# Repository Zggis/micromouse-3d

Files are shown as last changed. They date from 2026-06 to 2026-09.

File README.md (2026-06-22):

# :mouse2: Micromouse 3D

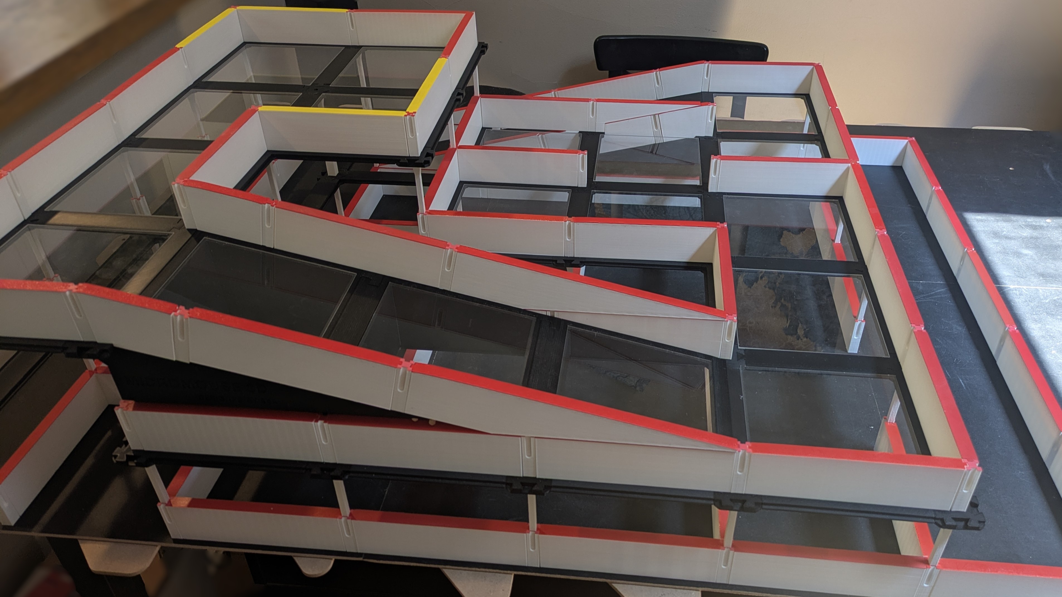
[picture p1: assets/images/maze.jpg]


Micromouse 3D builds off the traditional Micromouse event by using a multi-level maze.
The maze includes ramps that allow robots to travel between levels of the maze to reach the goal.
The cell dimensions are the same, most Micromouse robots won't require hardware changes to participate.
MM3D provides new challenges for students and enthusiasts over traditional Micromouse events.

If you are planning to build a MM3D maze, or participate in a MM3D event please star :star: this repository.
This will help me gauge interest in this project.

## :building_construction: [Maze Construction](./maze/README.md)

MM3D uses 3D printed parts to assemble the ramp and upper levels of the maze.
The parts have been designed to fit on standard 250mm size 3D printers.
All the print files are included in this repository, you can start [here](/maze/README.md) to build the maze.

> [!IMPORTANT]
> If you are planning to participate in a MM3D event,
> it is highly recommended you build a small test maze with a ramp so you can calibrate your robot.

## :scroll: [Rules](./rules/README.md)

Similar to traditional Micromouse, the rules for a MM3D event can be tuned to the level of difficulty desired. Two events are outlined in this repository 'Pyramid' and 'Bridge'. These events serve as a template which competition organizers can build on and make adjustments as needed.

Due to maze constraints, robots must meet the following size constraints for MM3D:
- Mice must be less than 12cm high
- Mice cannot reach over the walls

## Version Compatibility

>[!WARNING]
> Parts from different versions may not be compatible as updates are made.

Releases are published under a semantic version which you can find in [global.json](./global.json).
You can switch the version by selecting a different tag in the repository.
Release notes for each version can be found in [Releases.](https://github.com/Zggis/micromouse-3d/releases)

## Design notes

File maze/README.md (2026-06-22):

# :hammer: Building the Maze

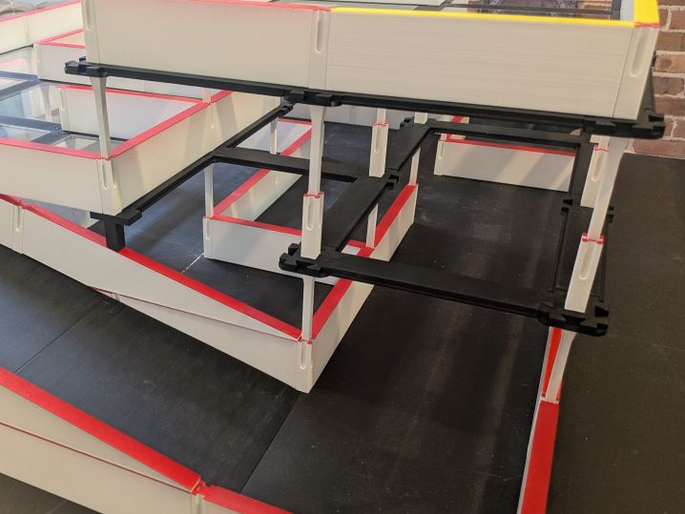
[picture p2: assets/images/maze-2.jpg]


MM3D can be used as a stand-alone maze or an add-on to an existing maze.

If you do not have a Micromomouse maze, you can use the parts [here](./base/) to create your base level.

All the 3D print files for MM3D are available in the subdirectories. Additional README files can be found in each directory explaining what the part is used for and the recommended print settings for it.

## :page_with_curl: Bill of Materials

In addition to parts you can 3D print, you can purchase the following:

| Part | Retail Link | |
|---|---|---|
| 15/64" x 1-1/4" (6mm) Wooden Dowel Pins | [Amazon](https://a.co/d/0eMDBzNE) | I recommend the RHINO brand to ensure the tolerances are compatible with the 3D printed parts. |
| Cyanoacrylate Glue (Super Glue) | [Amazon](https://a.co/d/03UX3yRg) | Used to glue pegs into the 3D printed pillars. |
| 6"x6" 1/8" Thick Clear Acrylic Sheets | [Amazon](https://a.co/d/02cTOcOn) | These are <strong>OPTIONAL</strong>, they can be substituted with a 3D printed [cell inserts](./inserts/). Using them is beneficial as it reduces 3D printing and allows you to see robots traveling on the levels below. |
| Base Tiles | [Shopify](https://swglobes.com/products/micromouse-maze-tile) | These are <strong>OPTIONAL</strong>, if you don't already have a maze they can be substituted with the 3D printed [base](./base/). These tiles are great for large mazes and fast robots that may not be able to perform on the 3D printed base. |

## :printer: Printing Guidelines

### File Types

This repository includes STL and STEP format files for 3D parts. STEP format includes more detail and should be used over STL if your slicer supports them. Popular slicers such as Bamboo Studio, Prusa Slicer, and Orca Slicer support STEP files.

### Print Settings & Orientation

If using the STEP files, slicers will ignore any coordinate system included in the file,
so you will need to orient them correctly using the recommended orientation included with the print settings.
These settings can be found in the README files in the corresponding component directories.
If you are confused about a part's print orientation, open the STL file which will be oriented correctly in the viewer.

### Dowel Holes

Some parts require you to insert 6mm wooden dowel pins.
The pins mentioned above can vary in diameter, I have measured between 5.60mm - 5.85mm.
To help accommodate this variation, all parts requiring pins are available with three different size holes.

> [!TIP]
> You can print the dowel test part in this directory to help you determine which size to use for which part.
> For the pillars, I recommend starting with a loose fit.
> For the vertex and ramp pieces, I recommend a very snug fit.
> From my experience, a batch of dowels is pretty consistent.
> If you switch batches, you should recheck the fit.

| Filename Suffix | Dowel Hole Diameter |
|---|---|
| _60 | 6.0mm |
| _61 | 6.1mm |
| _62 | 6.2mm |

> [!NOTE]
> If your pins don't work with these tolerances,
> you can [request a new size](https://github.com/zggis/micromouse-3d/issues/new?template=new-dowel-hole-diameter-request.md)
> and I will try to accommodate.
> I will only consider this for 6mm pins that are equal length to those in the bill of materials.

### Material

I printed all the parts in PLA. Other materials may cause parts to shrink and impact the tolerances. You can try to scale the parts up in your slicer to account for this, but I have not tested it.

> [!WARNING]
> Try to keep printed parts away from direct sunlight,
> the connectors in particular can warp if they are exposed to heat.

### Printer Calibration

Some of the printed parts rely on tolerances of 0.1mm.
I suggest printing a few [lattice](./lattice/) parts to check the tolerances
and make sure they fit together correctly before printing parts in bulk.
If you find the tolerances are too small or too large, try the following:
- Change your printer's nozzle. After enough prints, nozzles wear out and can't extrude lines thin enough to meet their specification.
- Perform a skew calibration on your printer. All of my printers have been calibrated using the free Calistar method you can find [here](https://github.com/dirtdigger/fleur_de_cali).

## Components

There are four main components to MM3D:

### [Ramp](./ramp/)

The MM3D ramp is divided into three printed sections which slide together.
You generally only need one ramp per level, but some event types may require more.

### [Supports](./supports/)

There are two ways you can support the upper levels of the maze:
+ Using pillars with integrated support. This requires less printing and does not take up cell space. They can be used on upper levels to support levels 3 and up. If your base uses 6mm diameter holes (or you are using the printed [base](./base/)), you can use these to support the second level as well.
+ Using the elevated cell which sits in an open cell. This requires more printing, but is compatible with any maze that meets the standard Micromouse dimensions.

### [Lattice Structure](./lattice/)

The lattice is made from connectors and vertices which form the cell grid on upper levels.

### [Cell Inserts](./inserts/)

For the cell inserts, you can use 6"x6" 1/8"
thick plastic sheets such as the clear acrylic sheets from the bill of materials above,
or you can print the cell inserts.

### OPTIONAL Components

[Special parts](./special/) and [Edge parts](./edges/) are optional to create more cells and improve aesthetic. Additional details can be found in their READMEs.

## Assembly

Once you have all the components, the assembly is pretty straightforward. Here are a few points:

- The ramp pieces slide together and can be inserted into the maze sliding the top piece up against a wall. The lower ramp edge should be right at the threshold of the cell.
- Make sure to orient the connectors and vertices correctly, the dovetails should face up, and the ledge on the connectors should face up to cradle the cell inserts.
- If using the support pillars, insert a pillar into the vertex before resting it on the support pillar.
- When assembling the lattice structure on top of support pillars, it may seem flimsy at first,
but as you connect everything it will become more rigid.

> [!TIP]
> You may be tempted to build your maze like a parking garage, maximizing the number of cells on each level.
> This makes it more difficult to calibrate a robot's IR sensors, and extract a robot when it becomes stuck.
> Try building mazes with empty spaces between the levels and create balconies.
> These mazes still have the challenge of MM3D, but make it easier to see robots traveling through them.
> Every vertex doesn't need four connectors, consider removing some to create more space to see and extract robots.
> The image of the maze at the top of this page is a good example.

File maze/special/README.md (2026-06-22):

# Special Parts

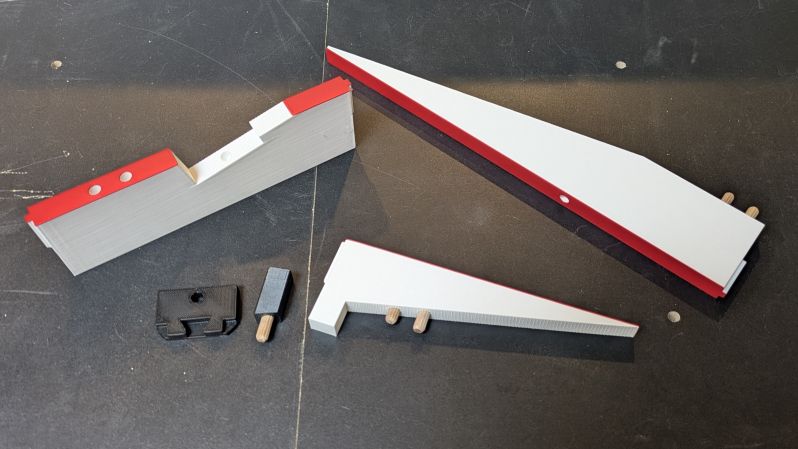
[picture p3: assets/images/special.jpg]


These parts are <strong>optional.</strong> They allow you
to add cells adjacent to and above ramps which would otherwise be unusable.
They may not be ideal for competition mazes,
but for test mazes that have a limited footprint they create more cells to work with.

## Print Settings

### Walls

- Middle walls should be printed upright, with the red surface on top. The other walls should be printed upside down with the red surfaces on the bed.

| Setting | Value | Reason |
|---|---|---|
| Perimeters / Wall Loops | 2 | |
| Infill | 10% | Using less than 10% may impact reflectivity |
| Solid Layers - Top & Bottom | 3 | No need for more than 3 on these parts, make sure your minimum shell thickness is small enough to support this. |
| Infill Type | Grid  | The walls are slightly translucent, using this infill pattern gives the best aesthetic and the most consistent reflectiveness. |

### Vertex and Vertex Spacer

- Vertex should be printed as it is in the maze with the dovetails facing up.
- Vertex spacer should be oriented, so it stands up straight with the slanted surface on top.

| Setting | Value | 
|---|---|
| Perimeters / Wall Loops | 3 | 
| Infill | 15% | 
| Solid Layers - TOP | 5 |

## Assembly

6mm dowel pins should be glued into the ramp-wall-half, not the ramp-wall-middle.

A dowel can be glued into the vertex spacer's slanted face.

2 drops of glue in each hole should be all that is needed.
<strong>The pins should be pressed in firmly, so they bottom out.</strong>

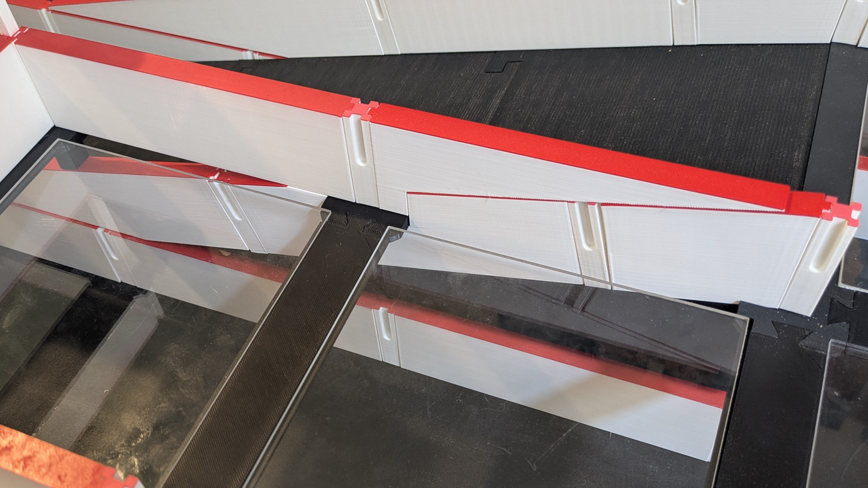
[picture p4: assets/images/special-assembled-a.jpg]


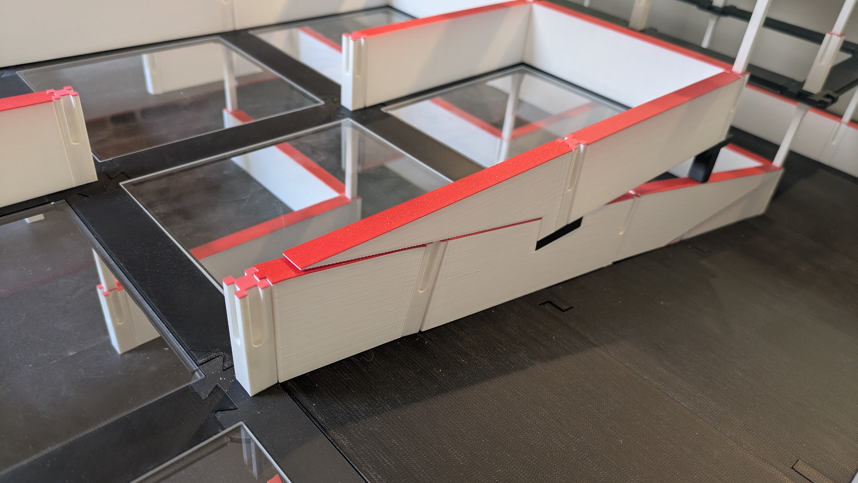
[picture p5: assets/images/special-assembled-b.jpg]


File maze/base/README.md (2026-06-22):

# Base Maze

If you don't already have a Micromouse maze, this vertex can be used with the [lattice](../lattice/) connectors and [cell inserts](../inserts/) to create a base level. This vertex is thicker to allow pillars to anchor into them without their pegs protruding.

Since it uses a 6mm peg hole, it is compatible with the support pillars, removing the need to use elevated cells.

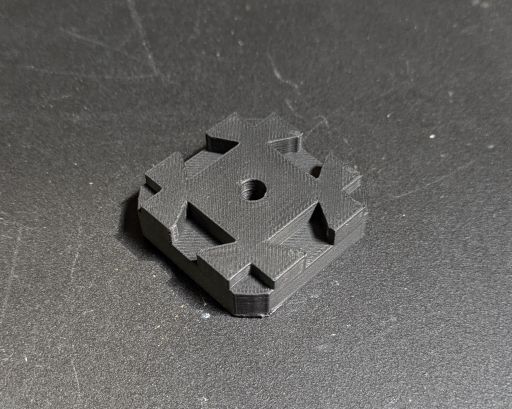
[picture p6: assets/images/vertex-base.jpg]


If you prefer not to the 3D print the base,
[these base tiles](https://swglobes.com/products/micromouse-maze-tile) are fully compatible with MM3D.

## Print Settings

Orient the part so the dovetails face up as they would when assembled.

| Setting | Value |
|---|---|
| Perimeters / Wall Loops | 2 |
| Infill | 5% | 
| Solid Layers - TOP | 5 |

## Assembly

> [!NOTE]
> If you are placing a ramp in a cell, inserts are not required underneath,
> the ramp can straddle the connectors.

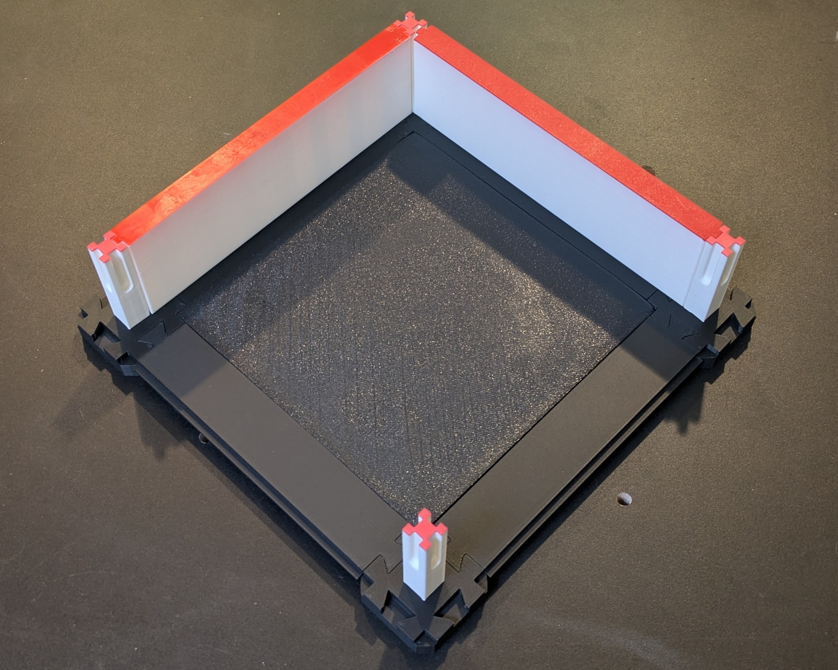
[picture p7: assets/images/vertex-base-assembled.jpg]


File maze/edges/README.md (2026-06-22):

# Edges

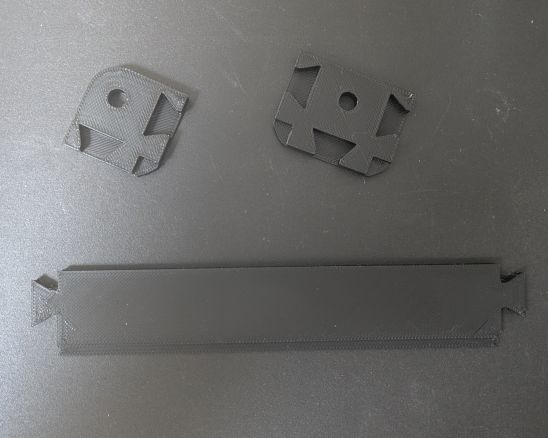
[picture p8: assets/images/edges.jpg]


These parts are <strong>optional.</strong> They can be used for the edges of the lattice to improve the aesthetic and save a small amount of filament.

## Print Settings

Use the same print settings as the corresponding [lattice](../lattice/) parts.

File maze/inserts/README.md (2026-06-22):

# Cell Insert

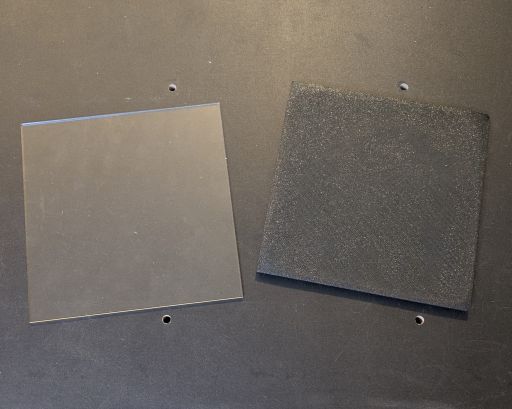
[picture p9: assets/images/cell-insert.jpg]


>[!NOTE]
> Cell inserts are not required for the elevated cell, or cells that have a ramp in them.

## Print Settings

Orient the part upside down with the top surface on the bed.

| Setting | Value | Reason |
|---|---|---|
| Perimeters / Wall Loops | 2 | |
| Infill | 5% | |
| Solid Layers - TOP | 5 | |
| Brim | 4mm | The corners have a tendency to warp off the bed, if you have this problem try using a 4mm brim |

## Plastic Panels

Any 1/8" thick 6"x6" panel should work as an insert. Clear acrylic panels are great because they allow you to see the robot as it travels on the levels below.

>[!WARNING]
> Cell inserts must be dimensionally accurate with high precision.
> Modern 3D printers have no trouble achieving this.
> If you are considering plastic panels from a retailer other than the one
> mentioned in the [Bill of Materials](../../maze/#page_with_curl-bill-of-materials),
> make sure the tolerances are precise before purchasing them.
> The insert frame has a +0.3mm tolerance;
> I have seen some plastic sheets online that claim a 1/16" tolerance, these may not be compatible.

While I have not tried it, you can also attempt to print cell inserts in translucent PLA.

The panels can be easily removed to extract your robot if it gets stuck.

## Assembly

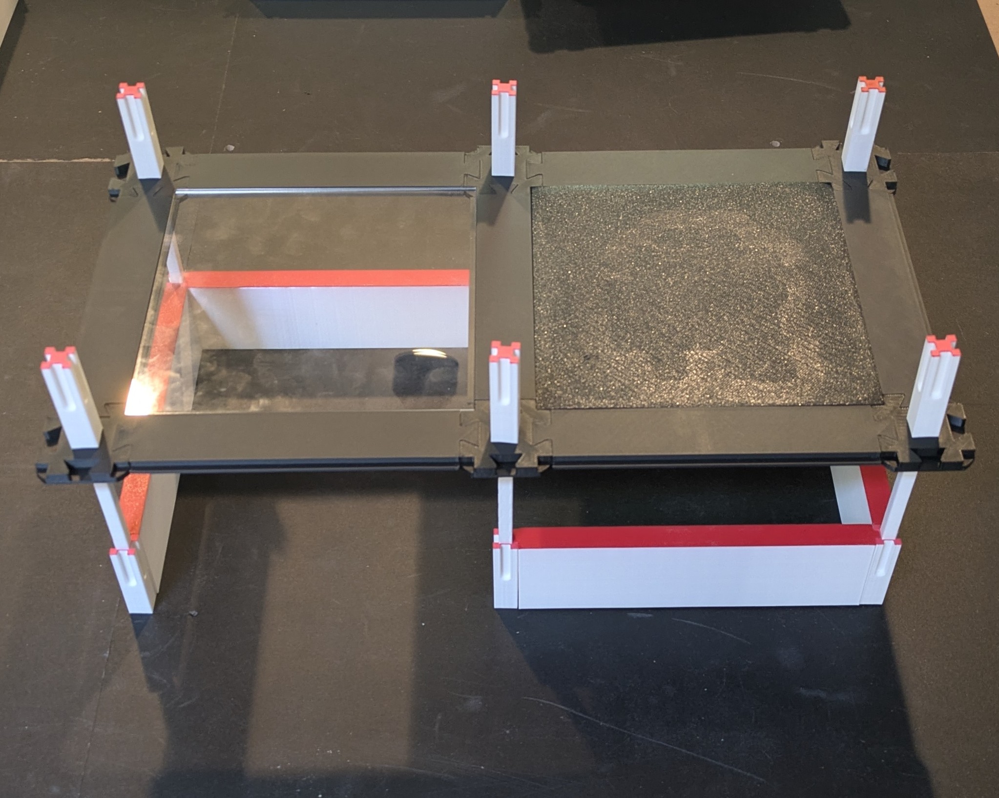
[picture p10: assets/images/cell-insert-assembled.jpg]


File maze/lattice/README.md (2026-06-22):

# Lattice Structure

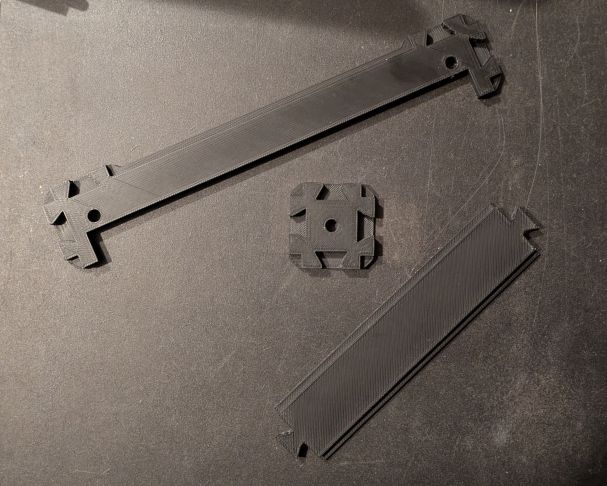
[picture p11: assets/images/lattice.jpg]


## Print Settings

- Orient the parts on the print bed as they are shown above.

| Setting | Value | Reason |
|---|---|---|
| Perimeters / Wall Loops | 3 | |
| Infill | 15% | These pieces need to span a gap, the extra infill and perimeters help to prevent drooping. |
| Solid Layers - TOP | 5 | |

## Assembly

> [!NOTE]
> If using the elevated cells, you do not need to print vertices for levels supported by the elevated cells.

The dovetails in the vertices should face up so the connectors slide down into them.

The connectors should have the insert slot facing up to it can cradle the cell insert and create a flush surface for the robots to travel.

Vertices support both standard and support pillars.

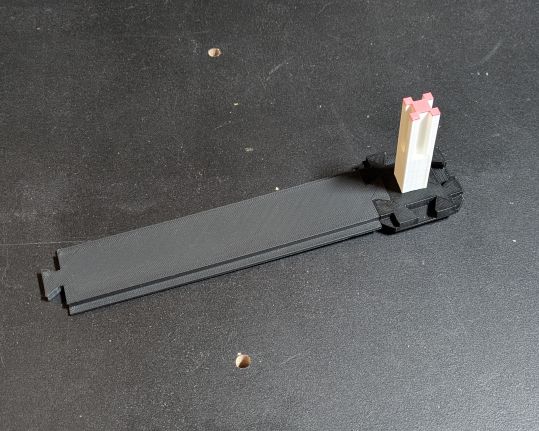
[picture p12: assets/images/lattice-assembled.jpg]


The ramp connector is secured to the ramp using pillars.

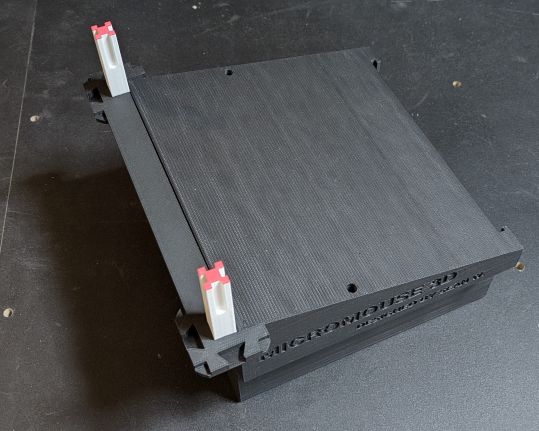
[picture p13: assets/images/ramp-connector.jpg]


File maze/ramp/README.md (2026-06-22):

# Ramp

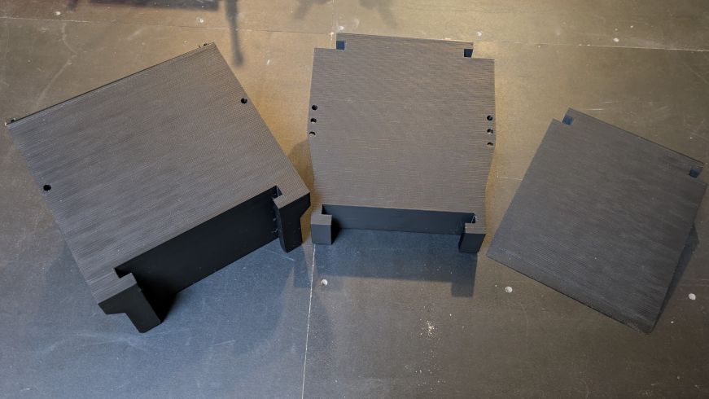
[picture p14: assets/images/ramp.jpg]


## Ramp Frame

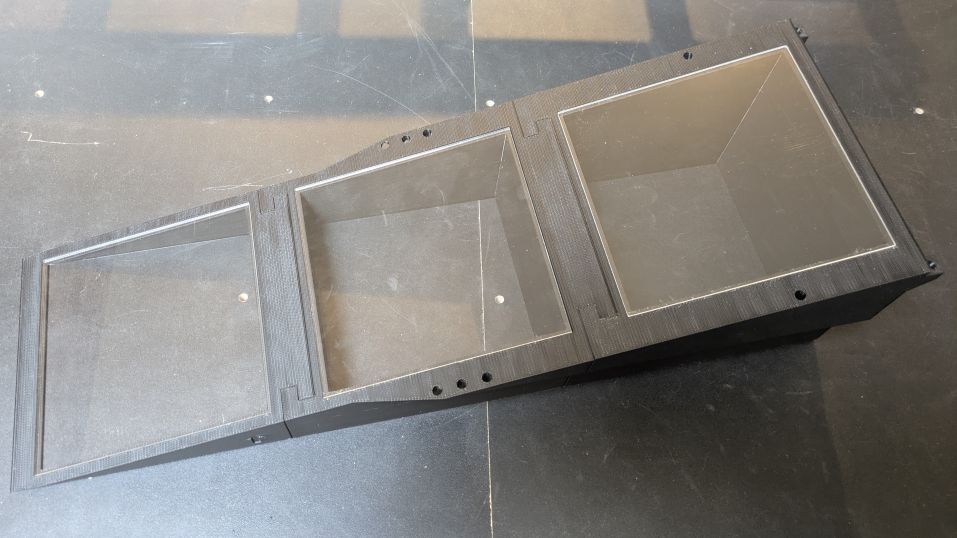
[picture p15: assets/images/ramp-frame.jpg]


Two types of ramps are available.
The ramp frame allows you to use the same clear acrylic panels as the cell inserts,
so you can see the levels below.
The frame ramp uses less filament and prints quicker,
but the solid ramp may be more suitable for competitions and robots that travel quickly.

> [!NOTE]
> You can mix and match ramp sections. For example, you can use a frame upper section with a solid middle.

## Print Settings

- Orient the ramp parts on the bed the same way they will sit in the maze.
- The lower ramp has an arrow on the side which should point up

| Setting | Value | Reason |
|---|---|---|
| Perimeters / Wall Loops | 2 | |
| Infill | 5% | These are large pieces that don't require substantial strength. |
| Minimum Shell Thickness - TOP | 1.2mm | This can also be achieved by setting top solid layers to 6 (assuming 0.2mm layer height). This helps to prevent pillowing on the travel surface. |
| Brim | 4mm | Ramp has small edges which can warp. |

## Assembly

The three ramp sections slide together, no glue is necessary.

To add walls to the ramp,
you can use the special ramp walls along with the standard pillars to anchor them into the ramp.
You can find all of these in the [walls](../walls/) directory.

To add the top pillars and connect the ramp to the lattice,
you will need the ramp vertex part which can be found in the [lattice](../lattice/) directory.

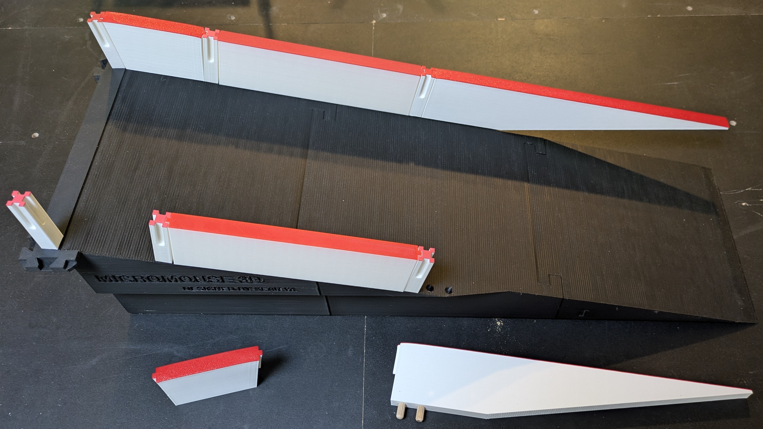
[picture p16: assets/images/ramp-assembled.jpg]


> [!NOTE]
> If you are placing a ramp on an upper level, cell inserts are not required underneath,
> the ramp can straddle the connectors.

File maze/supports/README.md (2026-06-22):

# Supports

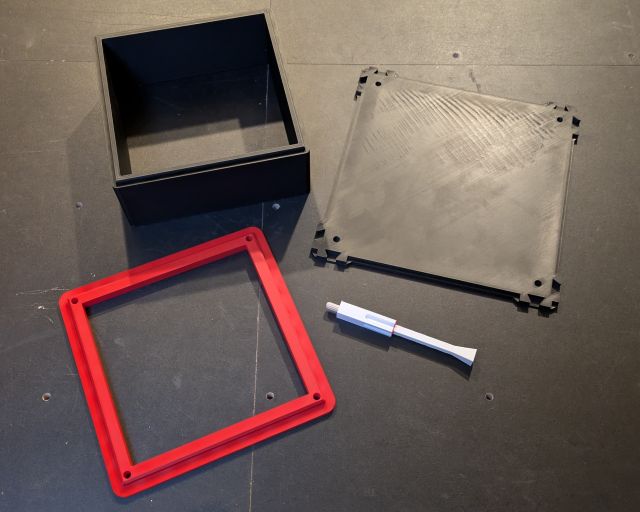
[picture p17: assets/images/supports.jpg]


## Print Settings

### Support Pillars

- Orient the support pillars on the bed the same way they will sit in the maze.

> [!WARNING]
> The support pillars are the most challenging part to print and tend to get knocked off the bed, especially when printing them in batches. To counter this, use an 8mm brim, enable Z-Hop or Lift Height (without ramping), and consider slowing down your print speed, perhaps using a height modified for the top. You should also ensure you have good bed adhesion, consider increasing your first layer print and bed temperatures.

| Setting | Value | Reason |
|---|---|---|
| Perimeters / Wall Loops | 3 | |
| Infill | 5% | |
| Solid Layers - Top & Bottom | 3 | No need for more than 3 on these parts, make sure your minimum shell thickness is small enough to support this. |
| Brim | 8mm | The pillars are tall with a small footprint, even with good bed adhesion a brim is highly recommended. | 

### Elevated Cell & Base

- Orient the elevated cell with the holes on the bed.
- The elevated cell base should have the chamfer facing up.

| Setting | Value | Reason |
|---|---|---|
| Perimeters / Wall Loops | 2 | |
| Infill | 5% | |

### Elevated Cell Top

- Orient the elevated cell top on the bed the same way it will sit in the maze with dovetails facing up.

| Setting | Value | Reason |
|---|---|---|
| Perimeters / Wall Loops | 3 | |
| Infill | 15% | |
| Solid Layers - TOP | 5 | |
| Bridging Angle | 45 | This part requires a small bridge, 45 degree angle ensures the bridge span is as small as possible for best results. |

## Assembly

6mm dowel pins should be glued into the pillars and elevated cell.
I recommend
using the dowels in the [Bill of Materials](../../maze/#page_with_curl-bill-of-materials) to ensure the best fit.

1 - 2 drops of glue per hole should be enough.



Attach the top and base to the elevated cell.

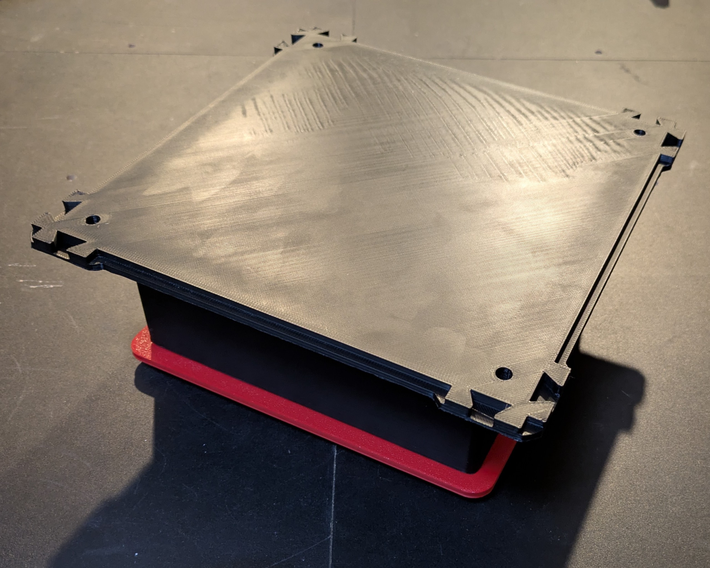
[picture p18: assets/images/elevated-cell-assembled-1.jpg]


The assembled elevated cell can sit in a closed off cell below.

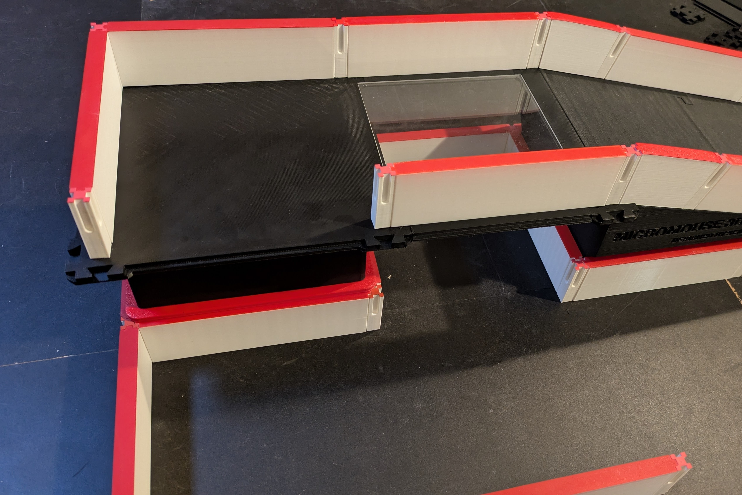
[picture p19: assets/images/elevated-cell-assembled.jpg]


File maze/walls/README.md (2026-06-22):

# Walls

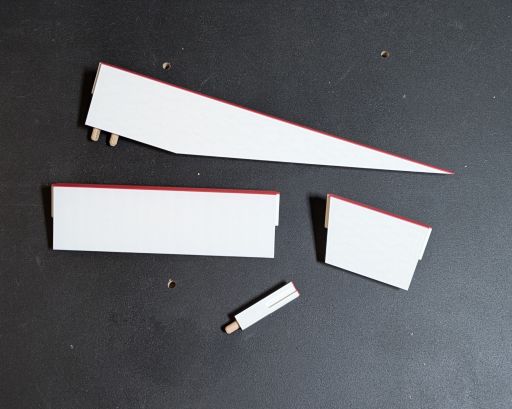
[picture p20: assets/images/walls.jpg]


## :rainbow: Multi Color

For walls and pillars, you may want to print the tops in red.
A wipe tower is not necessary since you can switch colors for the entire layer.
For mine, I printed three layers in red.
The walls are designed to be printed upside down,
so if you are doing a multi-color print you should separate the walls and pillars into different print jobs.

## Print Settings

### Walls

- Walls should be printed upside down with the red surfaces on the bed.
- You may need to rotate the lower ramp wall diagonally, so it can stretch between the corners of your bed given its size.

| Setting | Value | Reason |
|---|---|---|
| Perimeters / Wall Loops | 2 | |
| Infill | 10% | Using less than 10% may impact reflectivity |
| Solid Layers - Top & Bottom | 3 | No need for more than 3 on these parts, make sure your minimum shell thickness is small enough to support this. |
| Infill Type | Grid  | The walls are slightly translucent, using this infill pattern gives the best aesthetic and the most consistent reflectiveness. |

### Pillars

- Pillars should be oriented as they are in the maze with the peg hole on the bed.

| Setting | Value | Reason |
|---|---|---|
| Perimeters / Wall Loops | 2 | |
| Infill | 5% | |
| Solid Layers - TOP & Bottom | 3 | No need for more than 3 on these parts |
| Brim | 4mm | The pillars are tall with a small footprint, even with good bed adhesion a brim is highly recommended. |

## Assembly

6mm dowel pins should be glued into the pillars. I recommend using the dowels mentioned in the bill of materials to ensure the best fit.

2 drops of glue per pillar should be all that is needed. <strong>The pins should be pressed in firmly, so they bottom out in the pillar.</strong>

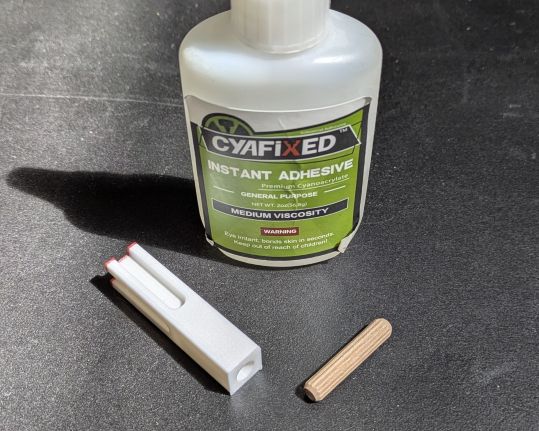
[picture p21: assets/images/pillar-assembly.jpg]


Walls slide down between two pillars

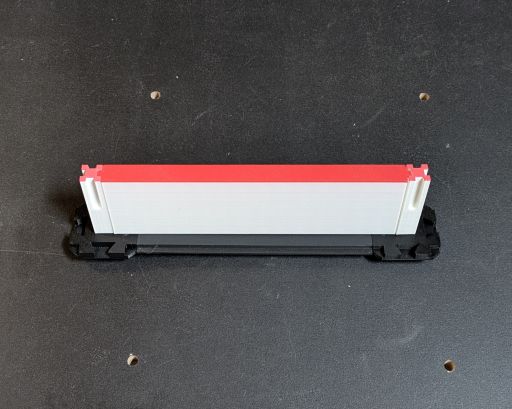
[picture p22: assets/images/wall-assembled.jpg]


For the lower ramp walls, two dowel pins should be glued into them, so they can be inserted into the ramp. <strong>The pins should be pressed in firmly, so they bottom out in the wall.</strong>



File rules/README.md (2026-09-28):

# Rules

Similar to traditional Micromouse, MM3D allows competitors to make certain assumptions about the maze.
These assumptions can be modified to change the level of difficulty for an event.
With traditional Micromouse, the goal is in a known location.
This assumption allows competitors to implement search algorithms to find it rather than relying on chance.
Knowing the goal location is important for beginner and intermediate competitions
where a robot may not be able to explore the entire maze and optimize a speed route in the allotted time.

For MM3D,
allowing competitors to know the location and orientation of ramps beforehand helps
to ensure their overall ranking won't be left to chance.
Without these assumptions,
a robot's decision
to make a left or right turn with no information can be the deciding factor in a competition.

Both events outlined below have fewer than the 256 cells required for traditional Micromouse events,
so they should not require additional memory for robots to participate.

> [!IMPORTANT]
> Do not assume every cell in the images below will be accessible and have a cell insert.
> Some cells from the upper levels might be removed to create more space to see and extract robots from the maze.
> Walls will block off these areas so robots can't reach them.

## Pyramid Event

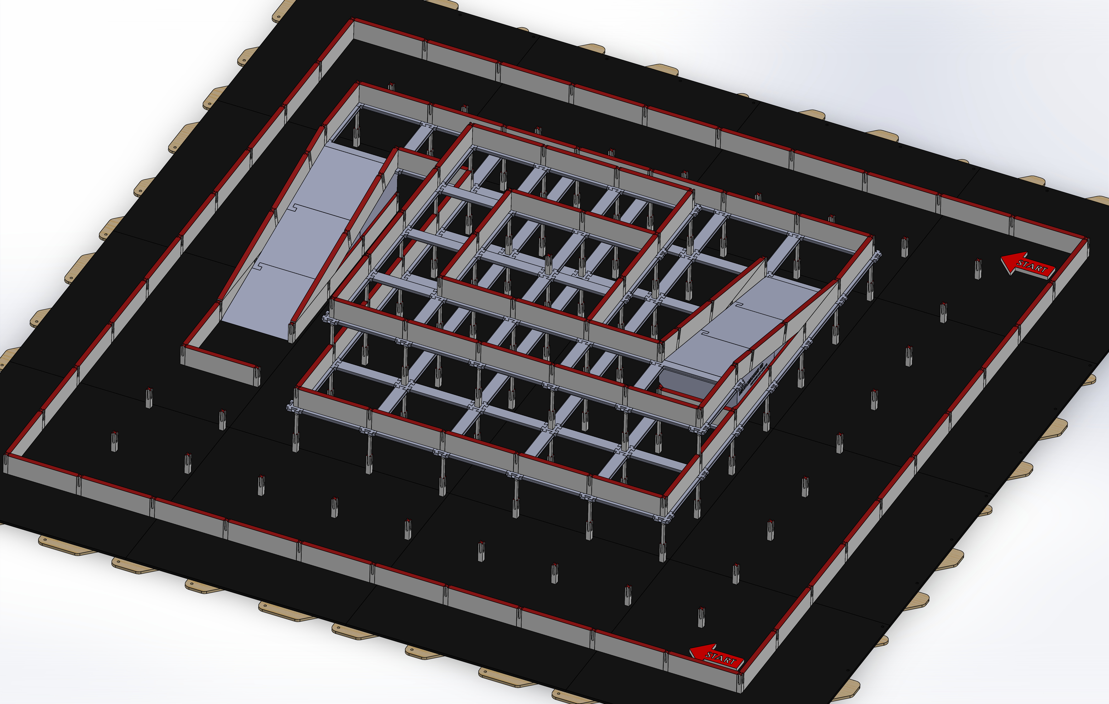
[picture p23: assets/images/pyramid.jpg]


The pyramid maze has three levels, each getting smaller with the goal at the center of the top level.
Each level has one ramp in a known location and a known orientation.

- The first level is a grid of 10 x 10 cells
- Second and third levels are smaller grids as seen in the image above.
- Both ramps will be in the positions and orientations seen in the image above.
- The starting location of robots will be on the lower level in one of two corner cells furthest from the ramp. Competitors will not know which cell prior, all robots will start in the same cell.
- The starting orientation of the robots would always be facing the ramp on the first level. See the red arrows in the image above.
- The starting cell will have three walls.
- Ramps will always let robots out into a corner cell as seen in the image.

[Here](pyramid.STL) is a 3D rendering of the pyramid maze including the position and orientation of its ramps. I recommend turning on the Surface Angle view. In this rendering (and the image above), all the walls you see are those which you can assume are present if the adjacent cell is accessible. One wall surrounding the goal will be absent.

- Rankings are determined by the fastest run time from the start cell to the goal.
- Robots that do not make it to the goal are ranked by the lowest flood fill value of their current position when picked up by an operator. <strong>NOT</strong> the lowest flood value they achieve during the run, this is too difficult for judges to keep track of.
  - The entire ramp is treated as a single cell for flood fill rankings. Robots that are picked up on the same ramp are effectively tied with their final rankings up to the discretion of the judges.
- Robots have 10 minutes in the maze to perform as many runs as they want.

## Bridge Event

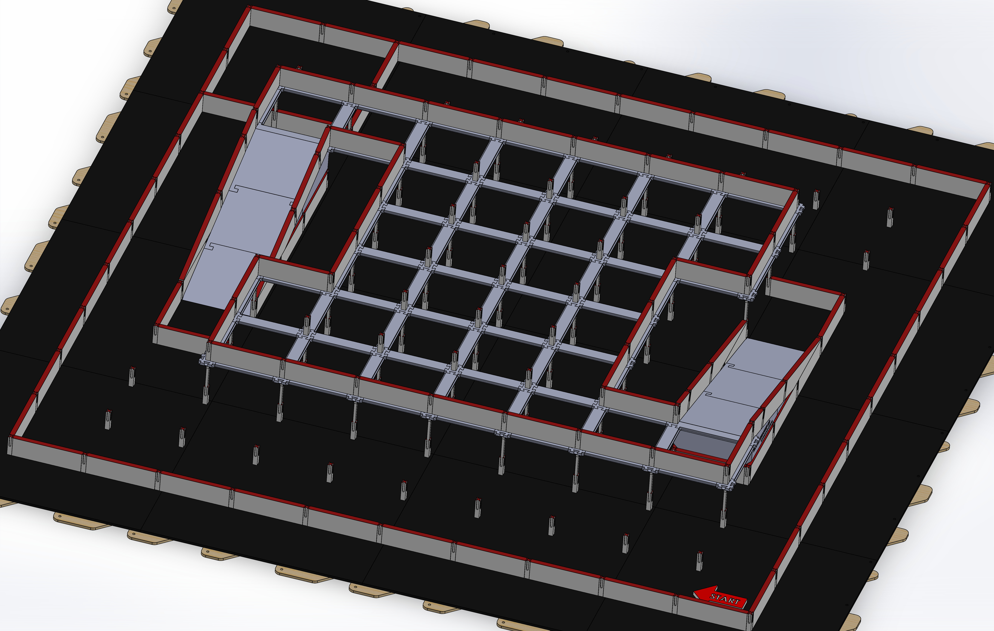
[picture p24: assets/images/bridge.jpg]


The bridge maze has two levels and two ramps.
The second level acts like a bridge which must be traversed to reach the goal.
The maze walls on the first level will be configured in such a way
reaching the goal will not be possible without traversing both ramps.

- First level is a grid of 10 x 10 cells
- Second level is a smaller grid of cells as seen in the image above.
- Both ramps will be in the positions and orientations seen in the image above.
- The goal is in the opposite corner the robot starts in on the first level
- Robots will start facing the first ramp they must traverse to reach the bridge. See the red arrow in the image above. Unlike the pyramid event, there is only one possible starting corner for robots.

[Here](bridge.STL) is a 3D rending of the bridge maze, including the position and orientation of its ramps. I recommend turning on the Surface Angle view. In this rendering (and the image above), all the walls you see are those which you can assume are present if the adjacent cell is accessible. One wall surrounding the goal will be absent.

> [!IMPORTANT]
> Do not make any assumptions about how the first level is divided up,
> or how many cells on the first level need to be traversed on either side of the bridge.

- Rankings are determined in the same way as the pyramid event above.
- Robots have 10 minutes in the maze to perform as many runs as they want.

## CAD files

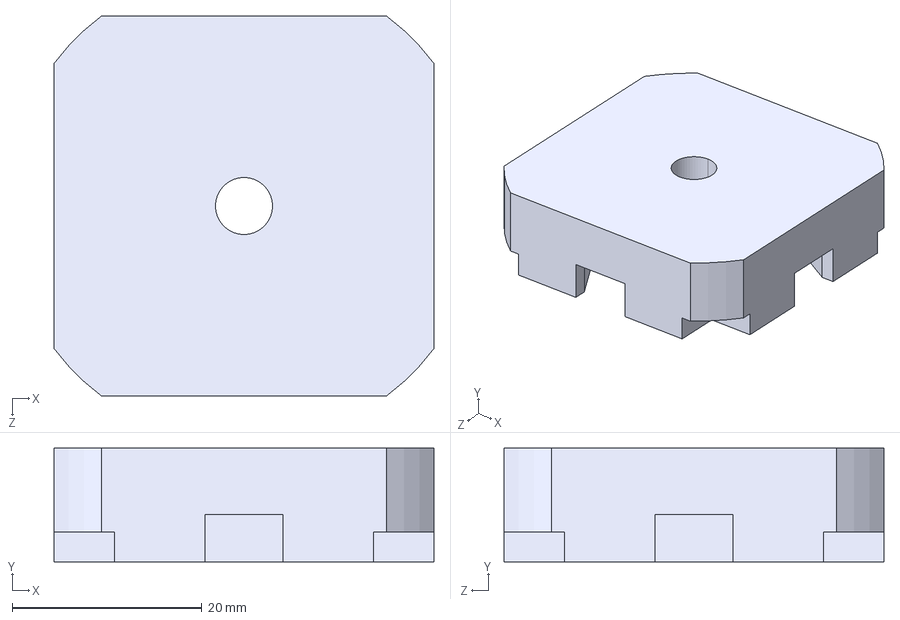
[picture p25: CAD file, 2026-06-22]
maze/base/vertex-base_60.STEP
40.0 x 12.0 x 40.0 mm

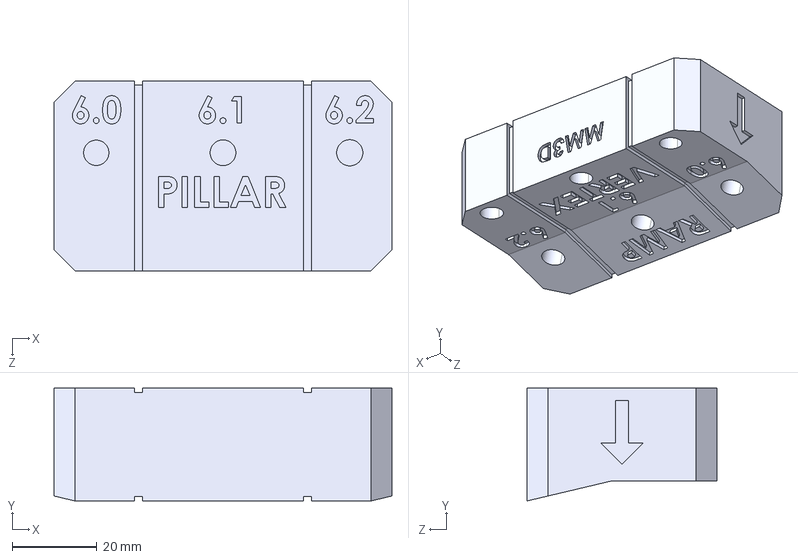
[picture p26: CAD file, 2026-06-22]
maze/dowel-tester.STEP
80.0 x 26.7 x 45.0 mm

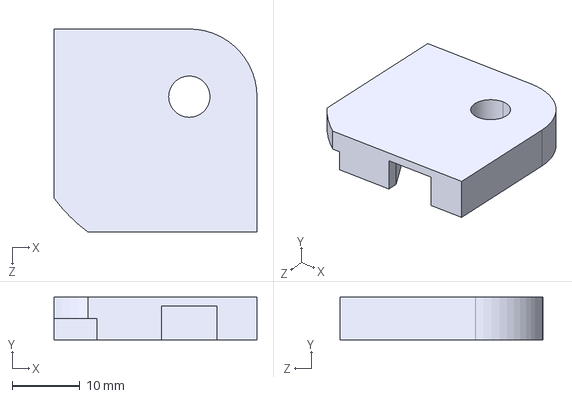
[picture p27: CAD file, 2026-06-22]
maze/edges/vertex-corner_61.STEP
30.0 x 6.35 x 30.0 mm

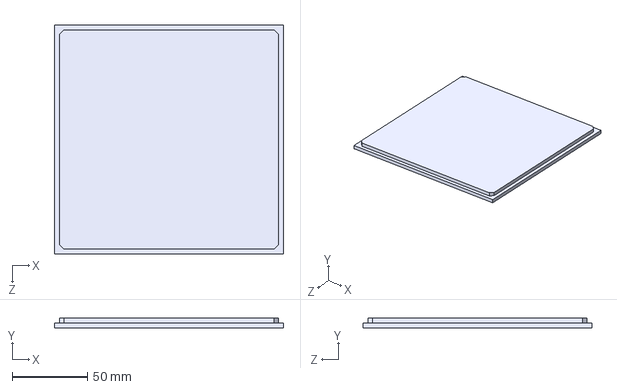
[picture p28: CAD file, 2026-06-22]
maze/inserts/cell-insert.STEP
152.4 x 6.35 x 152.4 mm

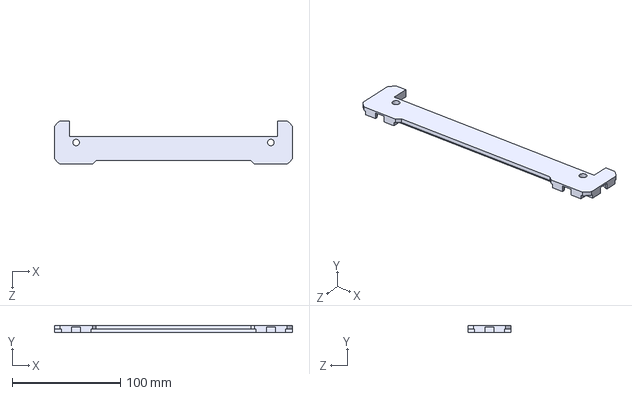
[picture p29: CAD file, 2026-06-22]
maze/lattice/ramp-vertex_61.STEP
220.0 x 6.35 x 40.0 mm

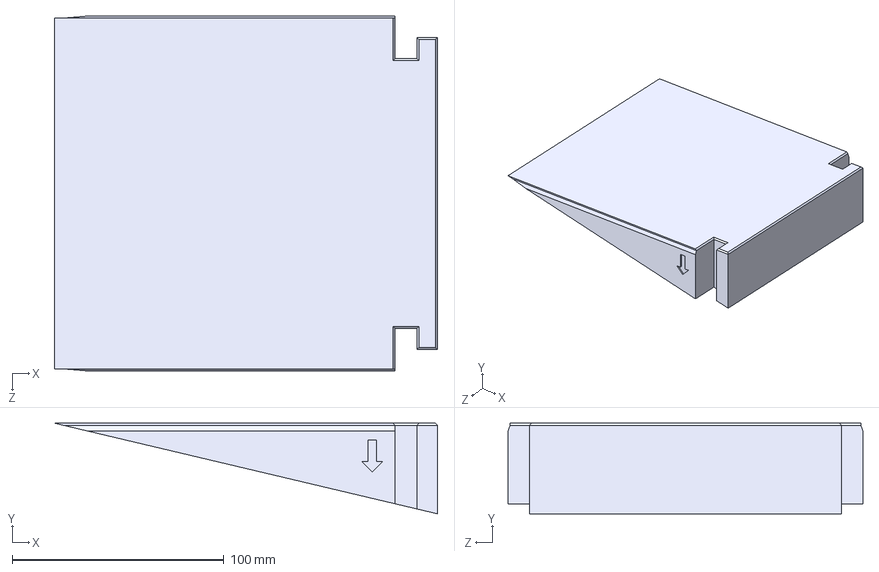
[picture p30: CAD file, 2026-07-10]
maze/ramp/ramp-lower.STEP
180.9 x 42.8 x 167.6 mm

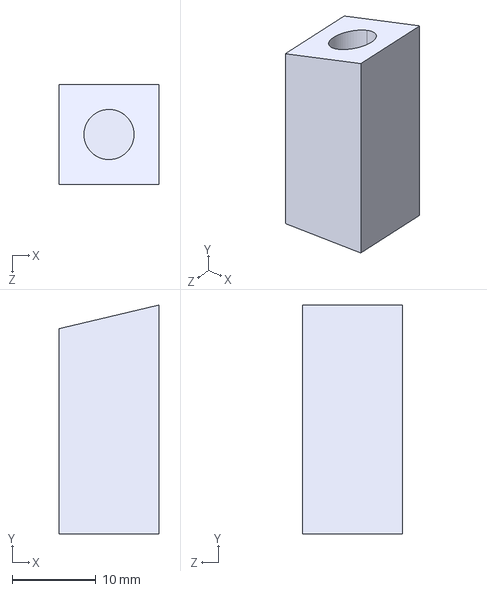
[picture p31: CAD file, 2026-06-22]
maze/special/vertex-spacer_60.STEP
12.0 x 27.4 x 12.0 mm

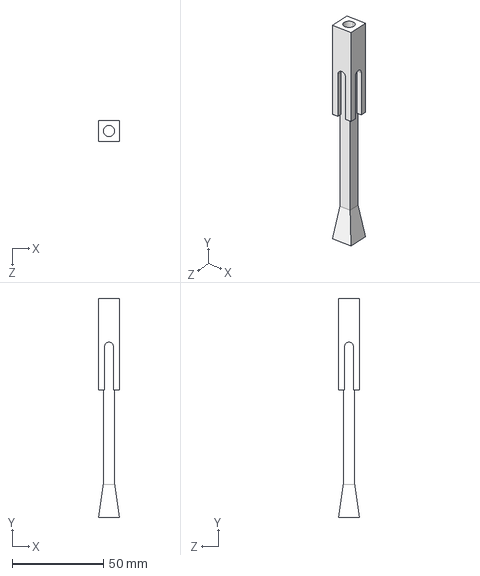
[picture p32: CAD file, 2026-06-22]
maze/supports/pillar-support_61.STEP
11.5 x 120.0 x 11.5 mm

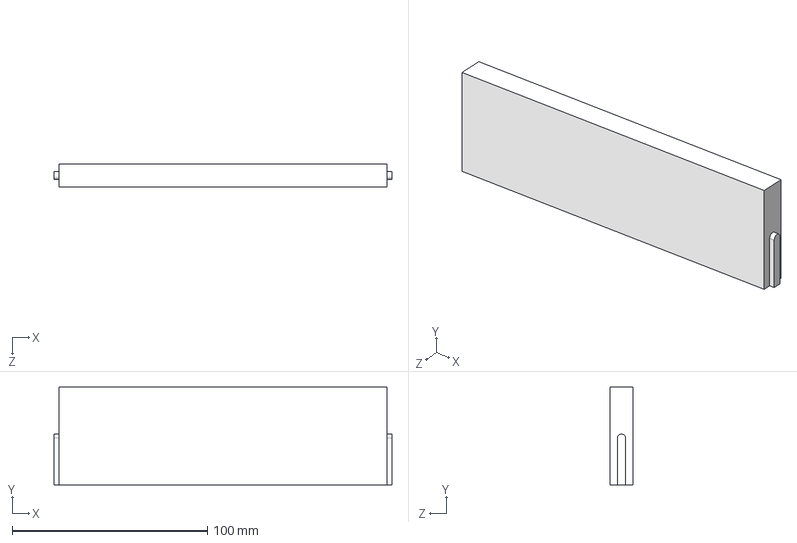
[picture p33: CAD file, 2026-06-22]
maze/walls/wall.STEP
173.0 x 50.0 x 12.0 mm

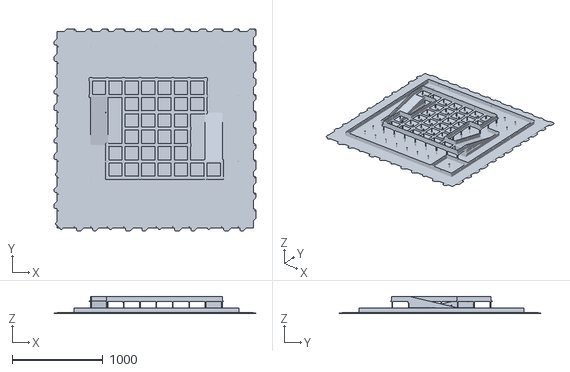
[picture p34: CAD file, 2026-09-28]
rules/bridge.STL
2220.0 x 2220.0 x 191.0

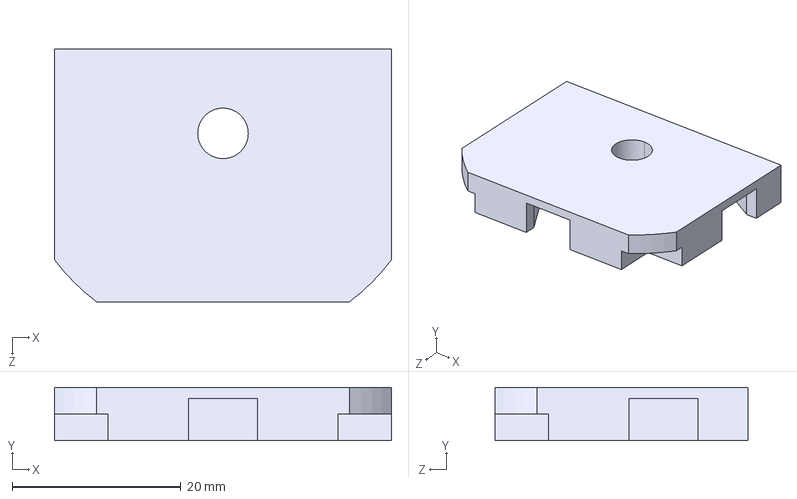
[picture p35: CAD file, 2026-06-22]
maze/edges/vertex-edge_60.STEP
40.0 x 6.35 x 30.0 mm

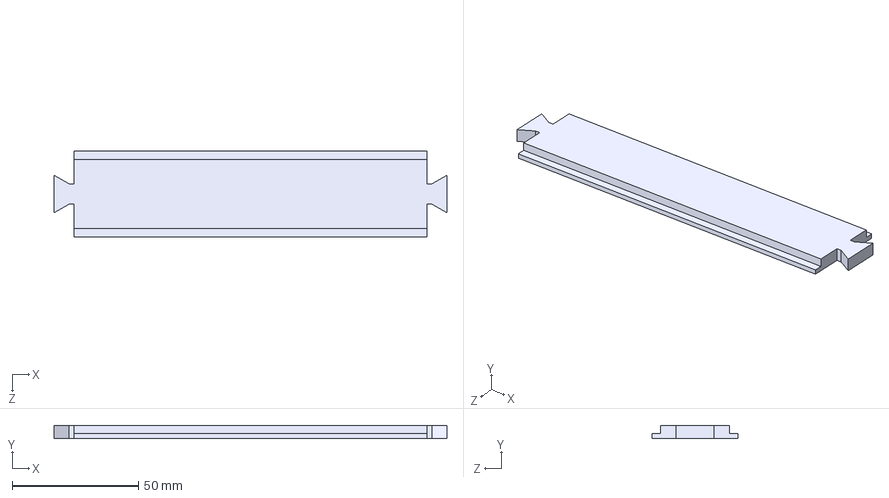
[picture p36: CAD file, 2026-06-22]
maze/lattice/connector.STEP
155.8 x 5.00 x 33.9 mm

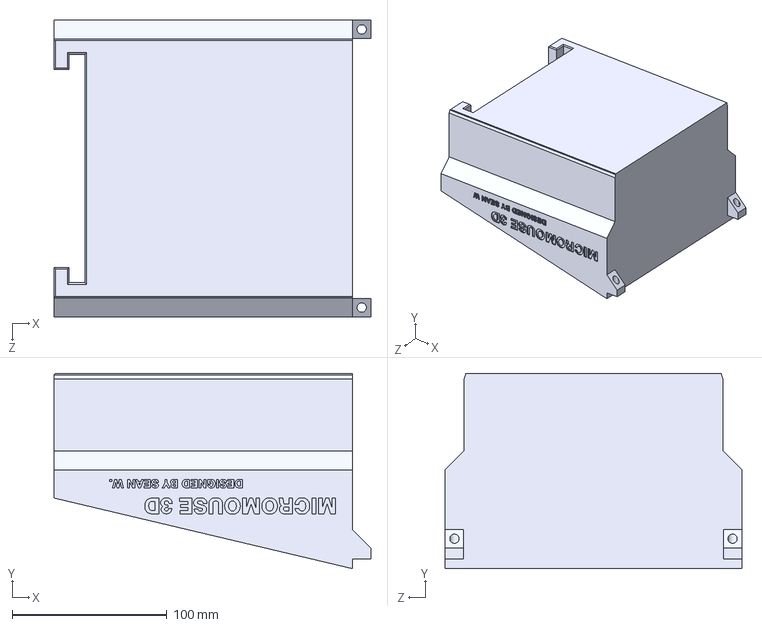
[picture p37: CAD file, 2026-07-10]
maze/ramp/ramp-upper_60.STEP
205.1 x 126.3 x 192.0 mm

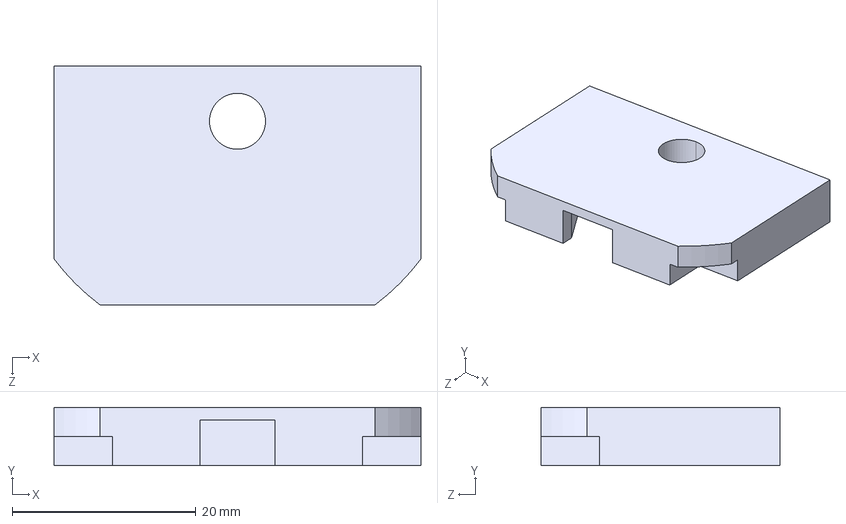
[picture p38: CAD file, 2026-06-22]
maze/special/vertex-single_61.STEP
40.0 x 6.35 x 26.0 mm

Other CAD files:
maze/base/vertex-base_61.STEP
maze/supports/elevated-cell_61.STEP
maze/walls/pillar_60.STEP
rules/pyramid.STL
maze/base/vertex-base_60.STL
maze/base/vertex-base_61.STL
maze/base/vertex-base_62.STEP
maze/base/vertex-base_62.STL
maze/dowel-tester.STL
maze/edges/connector-edge.STEP
maze/edges/connector-edge.STL
maze/edges/vertex-corner_60.STEP
maze/edges/vertex-corner_60.STL
maze/edges/vertex-corner_61.STL
maze/edges/vertex-corner_62.STEP
maze/edges/vertex-corner_62.STL
maze/edges/vertex-edge_60.STL
maze/edges/vertex-edge_61.STEP
maze/edges/vertex-edge_61.STL
maze/edges/vertex-edge_62.STEP
maze/edges/vertex-edge_62.STL
maze/inserts/cell-insert.STL
maze/lattice/connector.STL
maze/lattice/ramp-vertex_60.STEP
maze/lattice/ramp-vertex_60.STL
maze/lattice/ramp-vertex_61.STL
maze/lattice/ramp-vertex_62.STEP
maze/lattice/ramp-vertex_62.STL
maze/lattice/vertex_60.STEP
maze/lattice/vertex_60.STL
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

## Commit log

2026-06-22 Initial publication (#1)
    * Added 3D print files
    * Added documentation
    [bridge.STL, cell-insert.STEP, cell-insert.STL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]
2026-07-10 Fixed a 0.1mm tolerance on the ramps that would cause misalignment with pillar holes between levels (#2)
    [ramp-lower-frame.STEP, ramp-lower-frame.STL, ramp-lower.STEP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]
2026-09-28 Rules update (#4)
    Updated rules
    [bridge.STL, pyramid.STL]
